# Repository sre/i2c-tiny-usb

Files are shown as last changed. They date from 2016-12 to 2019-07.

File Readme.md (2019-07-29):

# I²C Tiny USB

This is my variant of i2c-tiny-usb from Dr. Till Harbaum. You
can find the original project on his homepage:

http://www.harbaum.org/till/i2c_tiny_usb/index.shtml

I modified the PCB schematics to fit my requirements and created
a nice case for it. The actual firmware for the ATtiny is exactly
the same. Instead of the ATtiny45 I used an ATtiny85, since it's
cheaper nowadays.

The PCB and the case are licensed under CC-BY 3.0:

https://creativecommons.org/licenses/by/3.0/

# Images

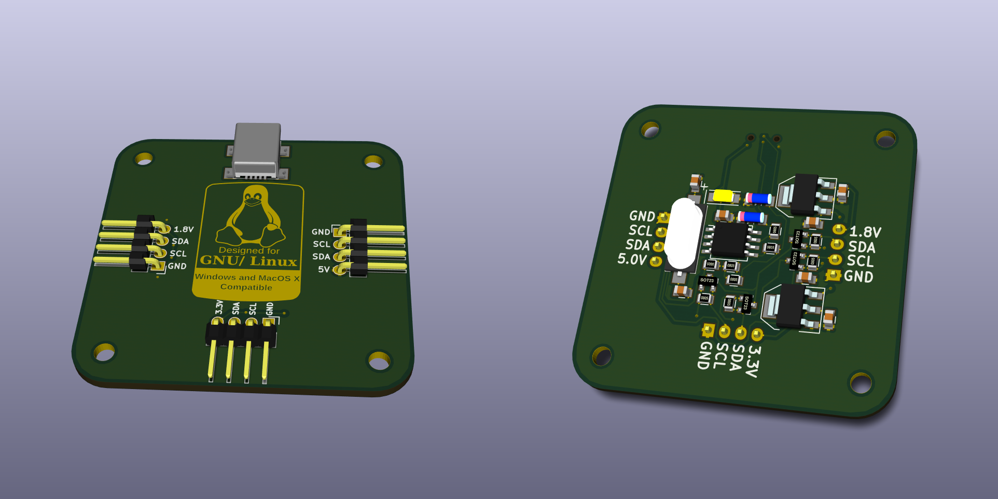
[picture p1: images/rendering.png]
Rendered PCB


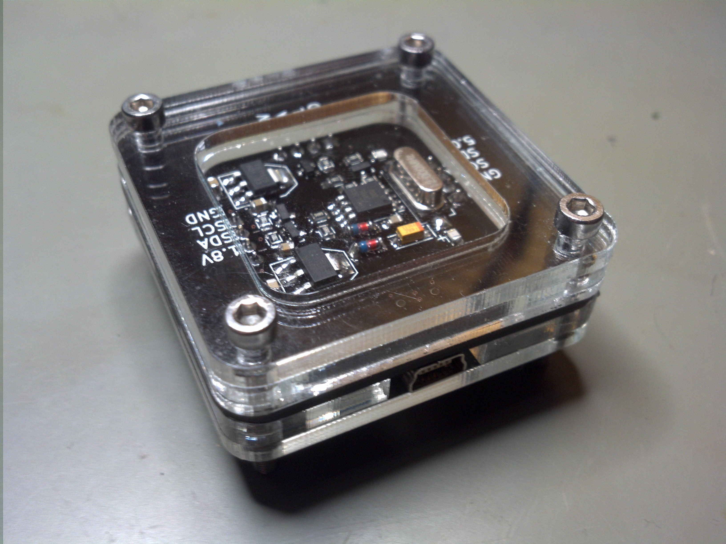
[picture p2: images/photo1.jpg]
PCB with Case Top


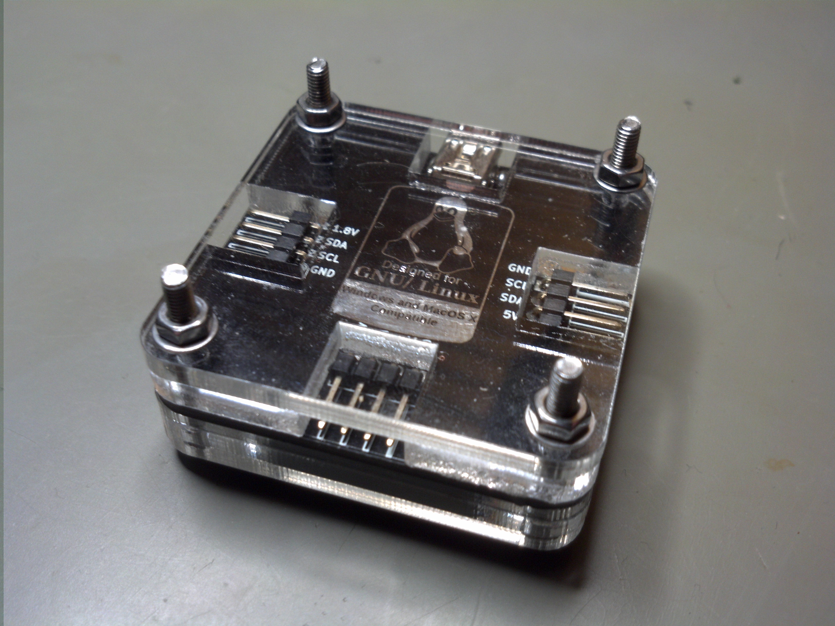
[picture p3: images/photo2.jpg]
PCB with Case Bottom


-- Sebastian Reichel <sre@ring0.de>

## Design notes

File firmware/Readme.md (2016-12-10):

i2c-tiny-usb - (c) 2006 by Till Harbaum 
---------------------------------------
http://www.harbaum.org/till/i2c_tiny_usb

The firmware code itself is distributed under the GPL, but the
usb driver is not. Plase see the .txt files in usbdrv for details.

The default configuration is for a attiny85.

The attiny85 has to be programmed in high voltage serial 
programming (hsvp) mode since this application needs the
reset pin to be reconfigured for other use. The first
time it can be programmed via ISP, though. Just connect
the reset pin to SCL, ground to USB GND, +5V to USB VCC,
clk to USB+, MISO to SDA and MOSI to USB-.

Just type `make all` or `make flash` to compile and upload
the file. Please adjust e.g. programmer settings in the Makefile.

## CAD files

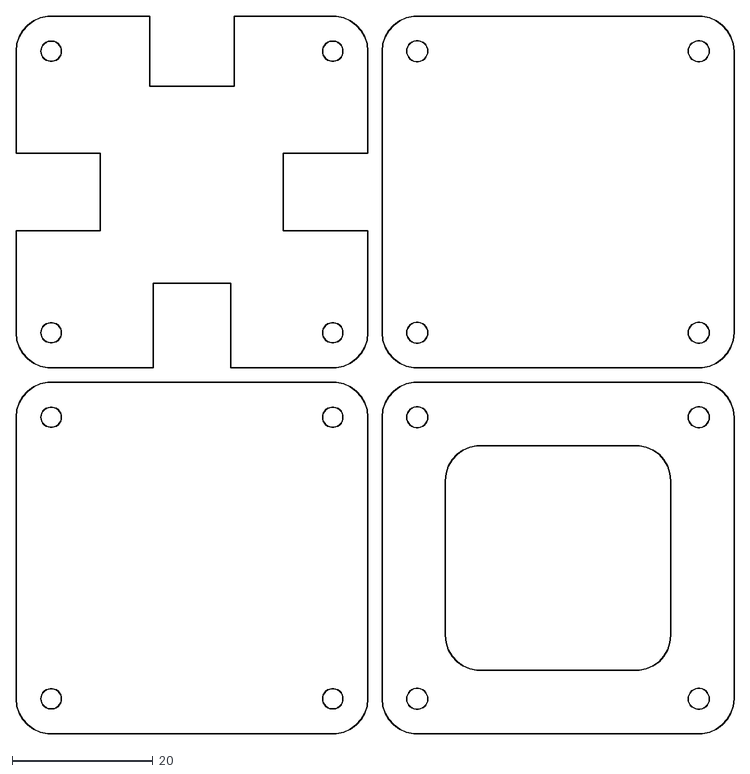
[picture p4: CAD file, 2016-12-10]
case/case.dxf
102.0 x 101.9

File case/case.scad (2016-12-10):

module round_square(size, radius) {
    hull() {
        translate([0+radius,0+radius]) scale([1/100, 1/100]) circle(radius * 100.0);
        translate([size[0]-radius,0+radius]) scale([1/100, 1/100]) circle(radius * 100.0);
        translate([0+radius,size[1]-radius]) scale([1/100, 1/100]) circle(radius * 100.0);
        translate([size[0]-radius,size[1]-radius]) scale([1/100, 1/100]) circle(radius * 100.0);
    }
}

module base(hole_diameter) {
    difference() {
        round_square([50,50], 5);
        translate([5,5]) scale([1/100, 1/100]) circle(d=hole_diameter*100.0);
        translate([45,5]) scale([1/100, 1/100]) circle(d=hole_diameter*100.0);
        translate([5,45]) scale([1/100, 1/100]) circle(d=hole_diameter*100.0);
        translate([45,45]) scale([1/100, 1/100]) circle(d=hole_diameter*100.0);
    }
}

module top2() {
    base(3.0);
}

module top1() {
    difference() {
        base(3.0);
        translate([9,9]) round_square([50-2*9,50-2*9], 5);
    }
}

module bottom1() {
    difference() {
        base(2.9);
        translate([25,50-10/2.0]) square(size=[12,10], center=true); // USB
        translate([12/2.0,25]) square(size=[12,11], center=true); // 5V I2C Port
        translate([50-12/2.0,25]) square(size=[12,11], center=true); // 1.8V I2C Port
        translate([25,12/2.0]) square(size=[11,12], center=true); // 3.3V I2C Port
    }
}

module bottom2() {
    base(2.9);
}

module all() {
    translate([0,0]) bottom2();
    translate([0,50+2]) bottom1();
    translate([50+2,0]) top1();
    translate([50+2,50+2]) top2();
}

all();

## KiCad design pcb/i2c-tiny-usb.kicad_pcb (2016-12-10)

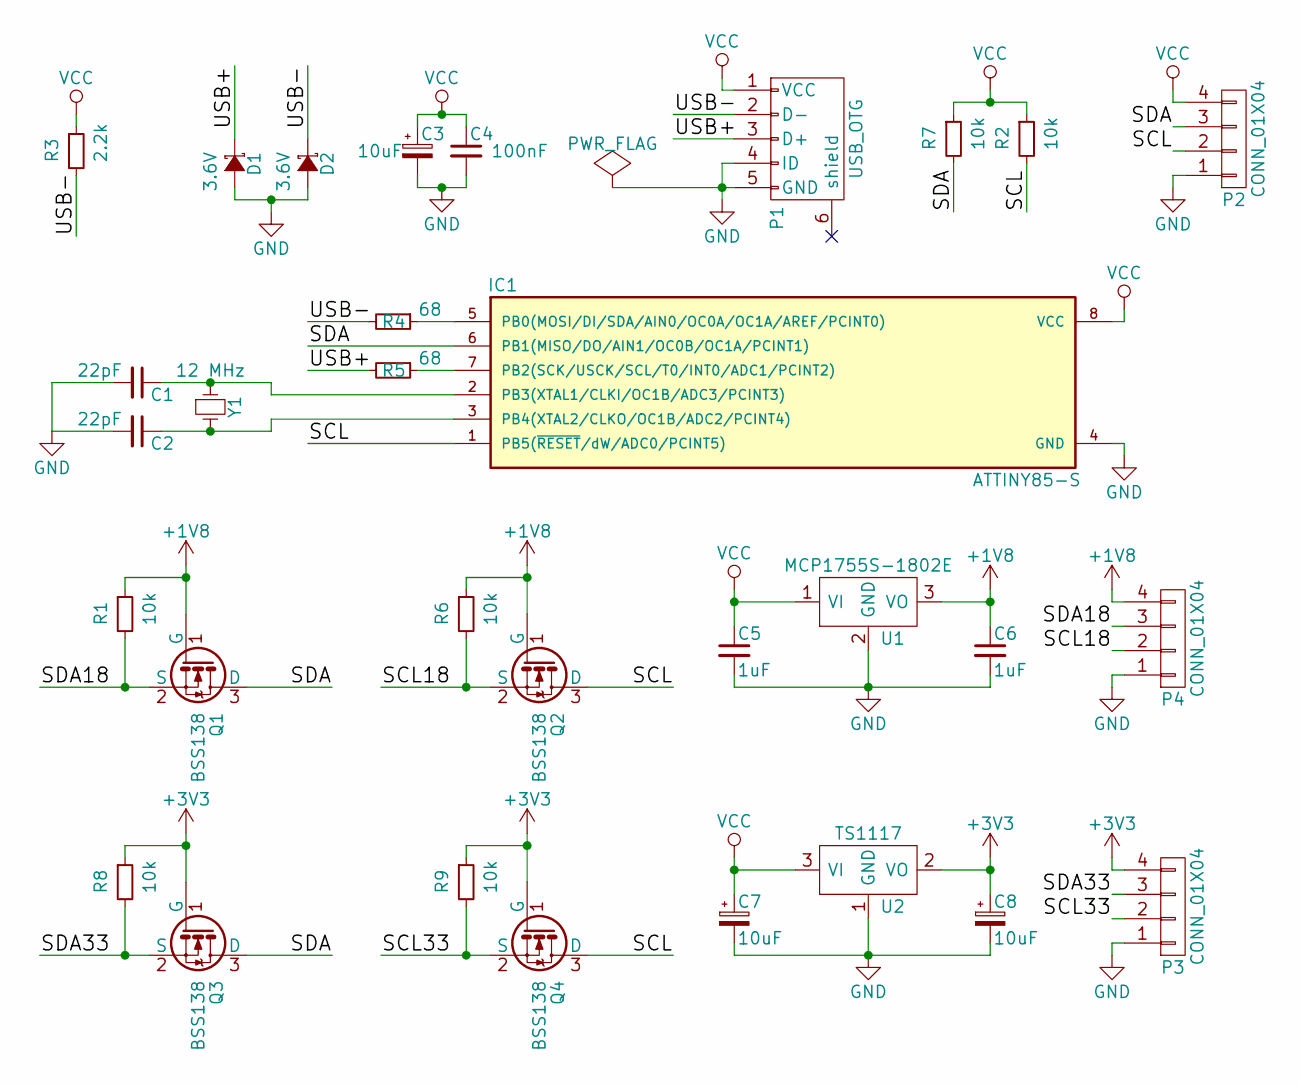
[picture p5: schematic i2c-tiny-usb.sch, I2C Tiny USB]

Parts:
C1, C2: 22pF; C_0805
C3: 10uF; TantalC_SizeA_EIA-3216_Wave
C4: 100nF; C_0805
C5, C6: 1uF; C_0805
C7, C8: 10uF; C_0805
D1, D2: 3.6V; MiniMELF_Standard
IC1: ATTINY85-S; SOIC-8-JEITA
P1: USB_OTG; USB_Mini-B
P2, P3, P4: CONN_01X04; Pin_Header_Angled_1x04
Q1, Q2, Q3, Q4: BSS138; SOT-23
R1, R2, R6, R7, R8, R9: 10k; R_0805
R3: 2.2k; R_0805
R4, R5: 68; R_0805
U1: MCP1755S-1802E; SOT-223
U2: TS1117; SOT-223
Y1: 12 MHz; Crystal_HC49-SD_SMD

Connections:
+1V8: C6.1, P4.4, Q1.1 (G), Q2.1 (G), R1.1, R6.1, U1.3 (VO)
+3V3: C8.1, P3.4, Q3.1 (G), Q4.1 (G), R8.1, R9.1, U2.2 (VO)
/SCL: IC1.1 (PB5(~RESET~/dW/ADC0/PCINT5)), P2.2, Q2.3 (D), Q4.3 (D), R2.2
/SCL18: P4.2, Q2.2 (S), R6.2
/SCL33: P3.2, Q4.2 (S), R9.2
/SDA: IC1.6 (PB1(MISO/DO/AIN1/OC0B/OC1A/PCINT1)), P2.3, Q1.3 (D), Q3.3 (D), R7.2
/SDA18: P4.3, Q1.2 (S), R1.2
/SDA33: P3.3, Q3.2 (S), R8.2
/USB+: D1.1 (K), P1.3 (D+), R5.2
/USB-: D2.1 (K), P1.2 (D-), R3.2, R4.2
GND: C1.2, C2.2, C3.2, C4.2, C5.2, C6.2, C7.2, C8.2, D1.2 (A), D2.2 (A), IC1.4 (GND), P1.4 (ID), P1.5 (GND), P2.1, P3.1, P4.1, U1.2 (GND), U2.1 (GND)
unnamed: C1.1, IC1.2 (PB3(XTAL1/CLKI/OC1B/ADC3/PCINT3)), Y1.1
unnamed: C2.1, IC1.3 (PB4(XTAL2/CLKO/OC1B/ADC2/PCINT4)), Y1.2
unnamed: IC1.5 (PB0(MOSI/DI/SDA/AIN0/OC0A/OC1A/AREF/PCI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), R4.1
unnamed: IC1.7 (PB2(SCK/USCK/SCL/T0/INT0/ADC1/PCINT2)), R5.1
VCC: C3.1, C4.1, C5.1, C7.1, IC1.8 (VCC), P1.1 (VCC), P2.4, R2.1, R3.1, R7.1, U1.1 (VI), U2.3 (VI)

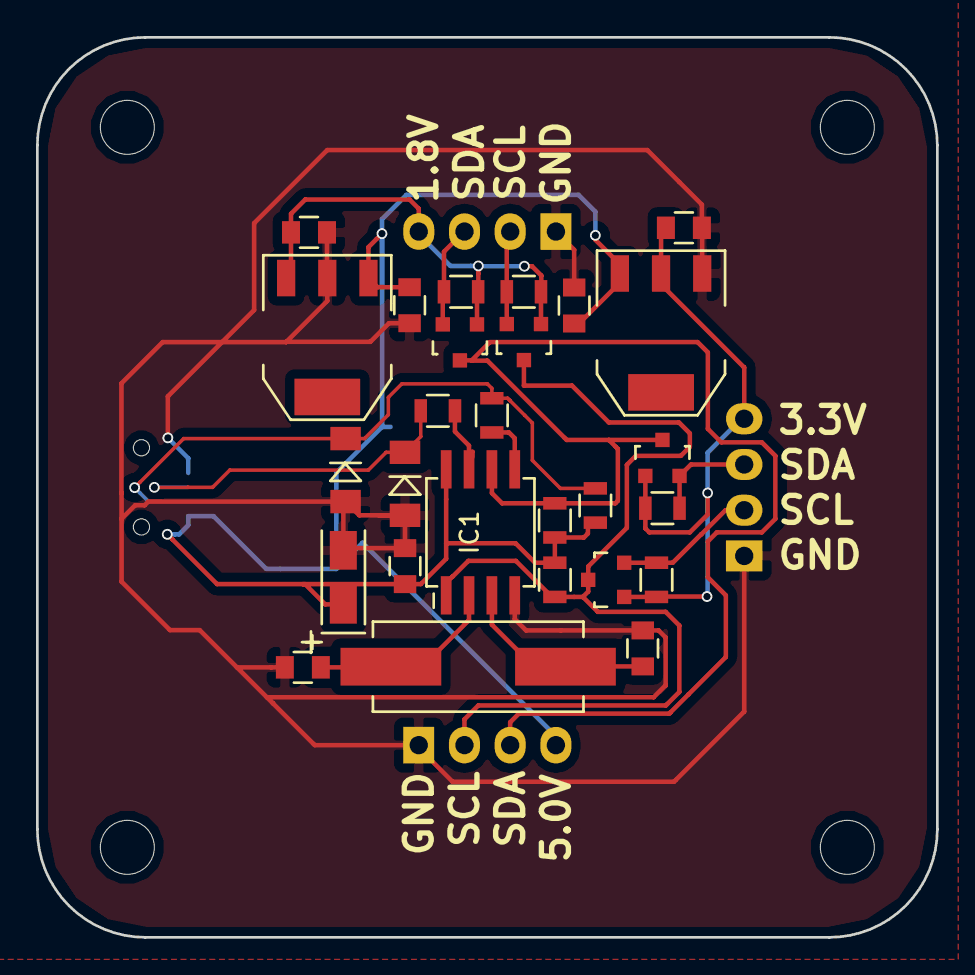
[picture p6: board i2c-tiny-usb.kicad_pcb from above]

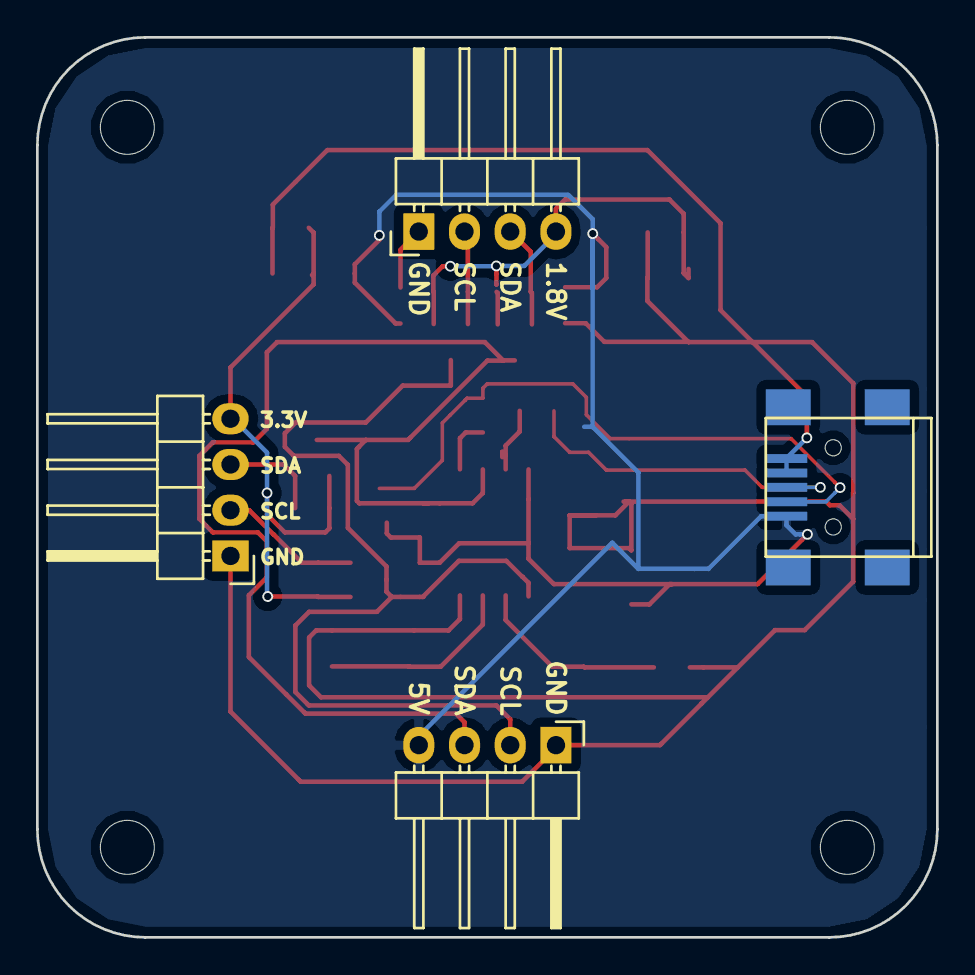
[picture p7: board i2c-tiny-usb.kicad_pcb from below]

Board: 2 copper layers, 50.0 x 50.0 mm, 31 parts (4 on the bottom side), 16 nets.

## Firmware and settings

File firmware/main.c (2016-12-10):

/* Name: main.c
 * Project: i2c-tiny-usb
 * Author: Till Harbaum
 * Tabsize: 4
 * Copyright: (c) 2005 by Till Harbaum <till@harbaum.org>
 * License: GPL
 * This Revision: $Id: main.c,v 1.9 2007/06/07 13:53:47 harbaum Exp $
 *
 * $Log: main.c,v $
 * Revision 1.9  2007/06/07 13:53:47  harbaum
 * Version number fixes
 *
 * Revision 1.8  2007/05/19 12:30:11  harbaum
 * Updated USB stacks
 *
 * Revision 1.7  2007/04/22 10:34:05  harbaum
 * *** empty log message ***
 *
 * Revision 1.6  2007/01/05 19:30:58  harbaum
 * i2c clock bug fix
 *
 * Revision 1.5  2007/01/03 18:35:07  harbaum
 * usbtiny fixes and pcb layouts
 *
 * Revision 1.4  2006/12/03 21:28:59  harbaum
 * *** empty log message ***
 *
 * Revision 1.3  2006/11/22 19:12:45  harbaum
 * Added usbtiny support
 *
 * Revision 1.2  2006/11/14 19:15:13  harbaum
 * *** empty log message ***
 *
 */

#include <stdio.h>
#include <ctype.h>
#include <string.h>

#include <avr/io.h>
#include <avr/interrupt.h>
#include <avr/pgmspace.h>
#include <avr/wdt.h>

#include <util/delay.h>

// use avrusb library
#include "usbdrv.h"
#include "oddebug.h"

#define ENABLE_SCL_EXPAND

/* commands from USB, must e.g. match command ids in kernel driver */
#define CMD_ECHO       0
#define CMD_GET_FUNC   1
#define CMD_SET_DELAY  2
#define CMD_GET_STATUS 3

#define CMD_I2C_IO     4
#define CMD_I2C_BEGIN  1  // flag fo I2C_IO
#define CMD_I2C_END    2  // flag fo I2C_IO

/* linux kernel flags */
#define I2C_M_TEN		0x10	/* we have a ten bit chip address */
#define I2C_M_RD		0x01
#define I2C_M_NOSTART		0x4000
#define I2C_M_REV_DIR_ADDR	0x2000
#define I2C_M_IGNORE_NAK	0x1000
#define I2C_M_NO_RD_ACK		0x0800

/* To determine what functionality is present */
#define I2C_FUNC_I2C			0x00000001
#define I2C_FUNC_10BIT_ADDR		0x00000002
#define I2C_FUNC_PROTOCOL_MANGLING	0x00000004 /* I2C_M_{REV_DIR_ADDR,NOSTART,..} */
#define I2C_FUNC_SMBUS_HWPEC_CALC	0x00000008 /* SMBus 2.0 */
#define I2C_FUNC_SMBUS_READ_WORD_DATA_PEC  0x00000800 /* SMBus 2.0 */ 
#define I2C_FUNC_SMBUS_WRITE_WORD_DATA_PEC 0x00001000 /* SMBus 2.0 */ 
#define I2C_FUNC_SMBUS_PROC_CALL_PEC	0x00002000 /* SMBus 2.0 */
#define I2C_FUNC_SMBUS_BLOCK_PROC_CALL_PEC 0x00004000 /* SMBus 2.0 */
#define I2C_FUNC_SMBUS_BLOCK_PROC_CALL	0x00008000 /* SMBus 2.0 */
#define I2C_FUNC_SMBUS_QUICK		0x00010000 
#define I2C_FUNC_SMBUS_READ_BYTE	0x00020000 
#define I2C_FUNC_SMBUS_WRITE_BYTE	0x00040000 
#define I2C_FUNC_SMBUS_READ_BYTE_DATA	0x00080000 
#define I2C_FUNC_SMBUS_WRITE_BYTE_DATA	0x00100000 
#define I2C_FUNC_SMBUS_READ_WORD_DATA	0x00200000 
#define I2C_FUNC_SMBUS_WRITE_WORD_DATA	0x00400000 
#define I2C_FUNC_SMBUS_PROC_CALL	0x00800000 
#define I2C_FUNC_SMBUS_READ_BLOCK_DATA	0x01000000 
#define I2C_FUNC_SMBUS_WRITE_BLOCK_DATA 0x02000000 
#define I2C_FUNC_SMBUS_READ_I2C_BLOCK	0x04000000 /* I2C-like block xfer  */
#define I2C_FUNC_SMBUS_WRITE_I2C_BLOCK	0x08000000 /* w/ 1-byte reg. addr. */
#define I2C_FUNC_SMBUS_READ_I2C_BLOCK_2	 0x10000000 /* I2C-like block xfer  */
#define I2C_FUNC_SMBUS_WRITE_I2C_BLOCK_2 0x20000000 /* w/ 2-byte reg. addr. */
#define I2C_FUNC_SMBUS_READ_BLOCK_DATA_PEC  0x40000000 /* SMBus 2.0 */
#define I2C_FUNC_SMBUS_WRITE_BLOCK_DATA_PEC 0x80000000 /* SMBus 2.0 */

#define I2C_FUNC_SMBUS_BYTE I2C_FUNC_SMBUS_READ_BYTE | \
                            I2C_FUNC_SMBUS_WRITE_BYTE
#define I2C_FUNC_SMBUS_BYTE_DATA I2C_FUNC_SMBUS_READ_BYTE_DATA | \
                                 I2C_FUNC_SMBUS_WRITE_BYTE_DATA
#define I2C_FUNC_SMBUS_WORD_DATA I2C_FUNC_SMBUS_READ_WORD_DATA | \
                                 I2C_FUNC_SMBUS_WRITE_WORD_DATA
#define I2C_FUNC_SMBUS_BLOCK_DATA I2C_FUNC_SMBUS_READ_BLOCK_DATA | \
                                  I2C_FUNC_SMBUS_WRITE_BLOCK_DATA
#define I2C_FUNC_SMBUS_I2C_BLOCK I2C_FUNC_SMBUS_READ_I2C_BLOCK | \
                                  I2C_FUNC_SMBUS_WRITE_I2C_BLOCK

#define I2C_FUNC_SMBUS_EMUL I2C_FUNC_SMBUS_QUICK | \
                            I2C_FUNC_SMBUS_BYTE | \
                            I2C_FUNC_SMBUS_BYTE_DATA | \
                            I2C_FUNC_SMBUS_WORD_DATA | \
                            I2C_FUNC_SMBUS_PROC_CALL | \
                            I2C_FUNC_SMBUS_WRITE_BLOCK_DATA | \
                            I2C_FUNC_SMBUS_WRITE_BLOCK_DATA_PEC | \
                            I2C_FUNC_SMBUS_I2C_BLOCK

/* the currently support capability is quite limited */
const unsigned long func PROGMEM = I2C_FUNC_I2C | I2C_FUNC_SMBUS_EMUL;

#ifdef DEBUG
#define DEBUGF(format, args...) printf_P(PSTR(format), ##args)

/* ------------------------------------------------------------------------- */
static int uart_putchar(char c, FILE *stream) {
  if (c == '\n')
    uart_putchar('\r', stream);
  loop_until_bit_is_set(UCSRA, UDRE);
  UDR = c;
  return 0;
}

static FILE mystdout = FDEV_SETUP_STREAM(uart_putchar, NULL,
                                         _FDEV_SETUP_WRITE);
#else
#define DEBUGF(format, args...)
#endif

/* ------------------------------------------------------------------------- */
#define DEFAULT_DELAY 10  // default 10us (100khz)
static unsigned short clock_delay  = DEFAULT_DELAY;
static unsigned short clock_delay2 = DEFAULT_DELAY/2;

static unsigned short expected;
static unsigned char saved_cmd;

#if! ( defined(__AVR_ATtiny45__) || defined(__AVR_ATtiny85__) )
#define I2C_PORT   PORTC
#define I2C_PIN    PINC
#define I2C_DDR    DDRC
#define I2C_SDA    _BV(4)
#define I2C_SCL    _BV(5)
#else
#define I2C_PORT   PORTB
#define I2C_PIN    PINB
#define I2C_DDR    DDRB
#define I2C_SDA    _BV(1)
#define I2C_SCL    _BV(5)
#endif

static void i2c_io_set_sda(uchar hi) {
  if(hi) {
    I2C_DDR  &= ~I2C_SDA;    // high -> input
    I2C_PORT |=  I2C_SDA;    // with pullup
  } else {
    I2C_DDR  |=  I2C_SDA;    // low -> output
    I2C_PORT &= ~I2C_SDA;    // drive low
  }
}

static uchar i2c_io_get_sda(void) {
  return(I2C_PIN & I2C_SDA);
}

static void i2c_io_set_scl(uchar hi) {
#ifdef ENABLE_SCL_EXPAND
  _delay_loop_2(clock_delay2);
  if(hi) {
    I2C_DDR &= ~I2C_SCL;          // port is input
    I2C_PORT |= I2C_SCL;          // enable pullup

    // wait while pin is pulled low by client
    while(!(I2C_PIN & I2C_SCL));
  } else {
    I2C_DDR |= I2C_SCL;           // port is output
    I2C_PORT &= ~I2C_SCL;         // drive it low
  }
  _delay_loop_2(clock_delay);
#else
  _delay_loop_2(clock_delay2);
  if(hi) I2C_PORT |=  I2C_SCL;    // port is high
  else   I2C_PORT &= ~I2C_SCL;    // port is low
  _delay_loop_2(clock_delay);
#endif
}

static void i2c_init(void) {
  /* init the sda/scl pins */
  I2C_DDR &= ~I2C_SDA;            // port is input
  I2C_PORT |= I2C_SDA;            // enable pullup
#ifdef ENABLE_SCL_EXPAND
  I2C_DDR &= ~I2C_SCL;            // port is input
  I2C_PORT |= I2C_SCL;            // enable pullup
#else
  I2C_DDR |= I2C_SCL;             // port is output
#endif

  /* no bytes to be expected */
  expected = 0;
}

/* clock HI, delay, then LO */
static void i2c_scl_toggle(void) {
  i2c_io_set_scl(1);
  i2c_io_set_scl(0);
}

/* i2c start condition */
static void i2c_start(void) {
  i2c_io_set_sda(0);
  i2c_io_set_scl(0);
}

/* i2c repeated start condition */
static void i2c_repstart(void) 
{
  /* scl, sda may not be high */
  i2c_io_set_sda(1);
  i2c_io_set_scl(1);
  
  i2c_io_set_sda(0);
  i2c_io_set_scl(0);
}

/* i2c stop condition */
static void i2c_stop(void) {
  i2c_io_set_sda(0);
  i2c_io_set_scl(1);
  i2c_io_set_sda(1);
}

static uchar i2c_put_u08(uchar b) {
  char i;

  for (i=7;i>=0;i--) {
    if ( b & (1<<i) )  i2c_io_set_sda(1);
    else               i2c_io_set_sda(0);
    
    i2c_scl_toggle();           // clock HI, delay, then LO
  }
  
  i2c_io_set_sda(1);            // leave SDL HI
  i2c_io_set_scl(1);            // clock back up

  b = i2c_io_get_sda();         // get the ACK bit
  i2c_io_set_scl(0);            // not really ??

  return(b == 0);               // return ACK value
}

static uchar i2c_get_u08(uchar last) {
  char i;
  uchar c,b = 0;

  i2c_io_set_sda(1);            // make sure pullups are activated
  i2c_io_set_scl(0);            // clock LOW

  for(i=7;i>=0;i--) {
    i2c_io_set_scl(1);          // clock HI
    c = i2c_io_get_sda();
    b <<= 1;
    if(c) b |= 1;
    i2c_io_set_scl(0);          // clock LO
  }

  if(last) i2c_io_set_sda(1);   // set NAK
  else     i2c_io_set_sda(0);   // set ACK

  i2c_scl_toggle();             // clock pulse
  i2c_io_set_sda(1);            // leave with SDL HI

  return b;                     // return received byte
}

#ifdef DEBUG
static void i2c_scan(void) {
  uchar i = 0;

  for(i=0;i<127;i++) {
    i2c_start();                  // do start transition
    if(i2c_put_u08(i << 1))       // send DEVICE address
      DEBUGF("I2C device at address 0x%x\n", i);

    i2c_stop();
  }
}
#endif

/* ------------------------------------------------------------------------- */

struct i2c_cmd {
  unsigned char type;
  unsigned char cmd;
  unsigned short flags;
  unsigned short addr;
  unsigned short len;  
};

#define STATUS_IDLE          0
#define STATUS_ADDRESS_ACK   1
#define STATUS_ADDRESS_NAK   2

static uchar status = STATUS_IDLE;

static uchar i2c_do(struct i2c_cmd *cmd) {
  uchar addr;

  DEBUGF("i2c %s at 0x%02x, len = %d\n", 
	   (cmd->flags&I2C_M_RD)?"rd":"wr", cmd->addr, cmd->len); 

  /* normal 7bit address */
  addr = ( cmd->addr << 1 );
  if (cmd->flags & I2C_M_RD )
    addr |= 1;

  if(cmd->cmd & CMD_I2C_BEGIN) 
    i2c_start();
  else 
    i2c_repstart();    

  // send DEVICE address
  if(!i2c_put_u08(addr)) {
    DEBUGF("I2C read: address error @ %x\n", addr);

    status = STATUS_ADDRESS_NAK;
    expected = 0;
    i2c_stop();
  } else {  
    status = STATUS_ADDRESS_ACK;
    expected = cmd->len;
    saved_cmd = cmd->cmd;

    /* check if transfer is already done (or failed) */
    if((cmd->cmd & CMD_I2C_END) && !expected) 
      i2c_stop();
  }

  /* more data to be expected? */
  return(cmd->len?0xff:0x00);
}

uchar	usbFunctionSetup(uchar data[8]) {
  static uchar replyBuf[4];
  usbMsgPtr = replyBuf;

  DEBUGF("Setup %x %x %x %x\n", data[0], data[1], data[2], data[3]);

  switch(data[1]) {

  case CMD_ECHO: // echo (for transfer reliability testing)
    replyBuf[0] = data[2];
    replyBuf[1] = data[3];
    return 2;
    break;

  case CMD_GET_FUNC:
    memcpy_P(replyBuf, &func, sizeof(func));
    return sizeof(func);
    break;

  case CMD_SET_DELAY:
    /* The delay function used delays 4 system ticks per cycle. */
    /* This gives 1/3us at 12Mhz per cycle. The delay function is */
    /* called twice per clock edge and thus four times per full cycle. */ 
    /* Thus it is called one time per edge with the full delay */ 
    /* value and one time with the half one. Resulting in */
    /* 2 * n * 1/3 + 2 * 1/2 n * 1/3 = n us. */
    clock_delay = *(unsigned short*)(data+2);
    if(!clock_delay) clock_delay = 1;
    clock_delay2 = clock_delay/2;
    if(!clock_delay2) clock_delay2 = 1;

    DEBUGF("request for delay %dus\n", clock_delay); 
    break;

  case CMD_I2C_IO:
  case CMD_I2C_IO + CMD_I2C_BEGIN:
  case CMD_I2C_IO                 + CMD_I2C_END:
  case CMD_I2C_IO + CMD_I2C_BEGIN + CMD_I2C_END:
    // these are only allowed as class transfers

    return i2c_do((struct i2c_cmd*)data);
    break;

  case CMD_GET_STATUS:
    replyBuf[0] = status;
    return 1;
    break;

  default:
    // must not happen ...
    break;
  }

  return 0;  // reply len
}


/*---------------------------------------------------------------------------*/
/* usbFunctionRead                                                           */
/*---------------------------------------------------------------------------*/

uchar usbFunctionRead( uchar *data, uchar len )
{
  uchar i;

  DEBUGF("read %d bytes, %d exp\n", len, expected);

  if(status == STATUS_ADDRESS_ACK) {
    if(len > expected) {
      DEBUGF("exceeds!\n");
      len = expected;
    }

    // consume bytes
    for(i=0;i<len;i++) {
      expected--;
      *data = i2c_get_u08(expected == 0);
      DEBUGF("data = %x\n", *data);
      data++;
    }

    // end transfer on last byte
    if((saved_cmd & CMD_I2C_END) && !expected) 
      i2c_stop();

  } else {
    DEBUGF("not in ack state\n");
    memset(data, 0, len);
  }
  return len;
}

/*---------------------------------------------------------------------------*/
/* usbFunctionWrite                                                          */
/*---------------------------------------------------------------------------*/

uchar usbFunctionWrite( uchar *data, uchar len )
{
  uchar i, err=0;

  DEBUGF("write %d bytes, %d exp\n", len, expected);

  if(status == STATUS_ADDRESS_ACK) {
    if(len > expected) {
      DEBUGF("exceeds!\n");
      len = expected;
    }

    // consume bytes
    for(i=0;i<len;i++) {
      expected--;
      DEBUGF("data = %x\n", *data);
      if(!i2c_put_u08(*data++))
	err = 1;
    }

    // end transfer on last byte
    if((saved_cmd & CMD_I2C_END) && !expected) 
      i2c_stop();

    if(err) {
      DEBUGF("write failed\n");
      //TODO: set status
    }

  } else {
    DEBUGF("not in ack state\n");
    memset(data, 0, len);
  }

  return len;
}


/* ------------------------------------------------------------------------- */

int	main(void) {
#if 1
  wdt_enable(WDTO_1S);

#if DEBUG_LEVEL > 0
  /* let debug routines init the uart if they want to */
  odDebugInit();
#else
#ifdef DEBUG
  /* quick'n dirty uart init */
  UCSRB |= _BV(TXEN);
  UBRRL = F_CPU / (19200 * 16L) - 1;
#endif
#endif

#ifdef DEBUG
  stdout = &mystdout;
#endif

  DEBUGF("i2c-tiny-usb - (c) 2006 by Till Harbaum\n");

  i2c_init();

#ifdef DEBUG
  i2c_scan();
#endif

  /* clear usb ports */
  USB_CFG_IOPORT   &= (uchar)~((1<<USB_CFG_DMINUS_BIT)|(1<<USB_CFG_DPLUS_BIT));

  /* make usb data lines outputs */
  USBDDR    |= ((1<<USB_CFG_DMINUS_BIT)|(1<<USB_CFG_DPLUS_BIT));

  /* USB Reset by device only required on Watchdog Reset */
  _delay_loop_2(40000);   // 10ms

  /* make usb data lines inputs */
  USBDDR &= ~((1<<USB_CFG_DMINUS_BIT)|(1<<USB_CFG_DPLUS_BIT));

  usbInit();

  sei();
  for(;;) {	/* main event loop */
    wdt_reset();
    usbPoll();
  }
#endif

  return 0;
}

/* ------------------------------------------------------------------------- */

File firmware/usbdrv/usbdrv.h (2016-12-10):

/* Name: usbdrv.h
 * Project: AVR USB driver
 * Author: Christian Starkjohann
 * Creation Date: 2004-12-29
 * Tabsize: 4
 * Copyright: (c) 2005 by OBJECTIVE DEVELOPMENT Software GmbH
 * License: GNU GPL v2 (see License.txt) or proprietary (CommercialLicense.txt)
 * This Revision: $Id: usbdrv.h,v 1.2 2007/05/19 12:30:11 harbaum Exp $
 */

#ifndef __usbdrv_h_included__
#define __usbdrv_h_included__
#include "usbconfig.h"
#include "iarcompat.h"

/*
Hardware Prerequisites:
=======================
USB lines D+ and D- MUST be wired to the same I/O port. D+ must (also) be
connected to INT0. D- requires a pullup of 1.5k to +3.5V (and the device
must be powered at 3.5V) to identify as low-speed USB device. A pullup of
1M SHOULD be connected from D+ to +3.5V to prevent interference when no USB
master is connected. We use D+ as interrupt source and not D- because it
does not trigger on keep-alive and RESET states.

As a compile time option, the 1.5k pullup resistor on D- can be made
switchable to allow the device to disconnect at will. See the definition of
usbDeviceConnect() and usbDeviceDisconnect() further down in this file.

Please adapt the values in usbconfig.h according to your hardware!

The device MUST be clocked at 12 MHz. This is more than the 10 MHz allowed by
an AT90S2313 powered at 4.5V. However, if the supply voltage to maximum clock
relation is interpolated linearly, an ATtiny2313 meets the requirement by
specification. In practice, the AT90S2313 can be overclocked and works well.


Limitations:
============
Robustness with respect to communication errors:
The driver assumes error-free communication. It DOES check for errors in
the PID, but does NOT check bit stuffing errors, SE0 in middle of a byte,
token CRC (5 bit) and data CRC (16 bit). CRC checks can not be performed due
to timing constraints: We must start sending a reply within 7 bit times.
Bit stuffing and misplaced SE0 would have to be checked in real-time, but CPU
performance does not permit that. The driver does not check Data0/Data1
toggling, but application software can implement the check.

Input characteristics:
Since no differential receiver circuit is used, electrical interference
robustness may suffer. The driver samples only one of the data lines with
an ordinary I/O pin's input characteristics. However, since this is only a
low speed USB implementation and the specification allows for 8 times the
bit rate over the same hardware, we should be on the safe side. Even the spec
requires detection of asymmetric states at high bit rate for SE0 detection.

Number of endpoints:
The driver supports up to four endpoints: One control endpoint (endpoint 0),
two interrupt-in (or bulk-in) endpoints (endpoint 1 and 3) and one
interrupt-out (or bulk-out) endpoint (endpoint 1). Please note that the USB
standard forbids bulk endpoints for low speed devices! Most operating systems
allow them anyway, but the AVR will spend 90% of the CPU time in the USB
interrupt polling for bulk data.
By default, only the control endpoint 0 is enabled. To get the other endpoints,
define USB_CFG_HAVE_INTRIN_ENDPOINT, USB_CFG_HAVE_INTRIN_ENDPOINT3 and/or
USB_CFG_IMPLEMENT_FN_WRITEOUT respectively (see usbconfig-prototype.h for
details).

Maximum data payload:
Data payload of control in and out transfers may be up to 254 bytes. In order
to accept payload data of out transfers, you need to implement
'usbFunctionWrite()'.

USB Suspend Mode supply current:
The USB standard limits power consumption to 500uA when the bus is in suspend
mode. This is not a problem for self-powered devices since they don't need
bus power anyway. Bus-powered devices can achieve this only by putting the
CPU in sleep mode. The driver does not implement suspend handling by itself.
However, the application may implement activity monitoring and wakeup from
sleep. The host sends regular SE0 states on the bus to keep it active. These
SE0 states can be detected by wiring the INT1 pin to D-. It is not necessary
to enable the interrupt, checking the interrupt pending flag should suffice.
Before entering sleep mode, the application should enable INT1 for a wakeup
on the next bus activity.

Operation without an USB master:
The driver behaves neutral without connection to an USB master if D- reads
as 1. To avoid spurious interrupts, we recommend a high impedance (e.g. 1M)
pullup resistor on D+. If D- becomes statically 0, the driver may block in
the interrupt routine.

Interrupt latency:
The application must ensure that the USB interrupt is not disabled for more
than 20 cycles. This implies that all interrupt routines must either be
declared as "INTERRUPT" instead of "SIGNAL" (see "avr/signal.h") or that they
are written in assembler with "sei" as the first instruction.

Maximum interrupt duration / CPU cycle consumption:
The driver handles all USB communication during the interrupt service
routine. The routine will not return before an entire USB message is received
and the reply is sent. This may be up to ca. 1200 cycles = 100us if the host
conforms to the standard. The driver will consume CPU cycles for all USB
messages, even if they address another (low-speed) device on the same bus.

*/

/* ------------------------------------------------------------------------- */
/* --------------------------- Module Interface ---------------------------- */
/* ------------------------------------------------------------------------- */

#define USBDRV_VERSION  20070319
/* This define uniquely identifies a driver version. It is a decimal number
 * constructed from the driver's release date in the form YYYYMMDD. If the
 * driver's behavior or interface changes, you can use this constant to
 * distinguish versions. If it is not defined, the driver's release date is
 * older than 2006-01-25.
 */

#ifndef __ASSEMBLER__

#ifndef uchar
#define uchar   unsigned char
#endif
#ifndef schar
#define schar   signed char
#endif
/* shortcuts for well defined 8 bit integer types */

struct usbRequest;  /* forward declaration */
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

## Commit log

2016-12-10 initial pcb design
    [i2c-tiny-usb.kicad_pcb, i2c-tiny-usb.sch]
2016-12-10 add gerber files
    [i2c-tiny-usb-B.Cu.gbr, i2c-tiny-usb-B.Mask.gbr, i2c-tiny-usb-B.SilkS.gbr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]
2016-12-10 add case design
    [case.dxf, case.scad]
2019-07-29 Add photo from pcb + case

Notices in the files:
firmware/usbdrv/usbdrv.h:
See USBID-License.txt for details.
